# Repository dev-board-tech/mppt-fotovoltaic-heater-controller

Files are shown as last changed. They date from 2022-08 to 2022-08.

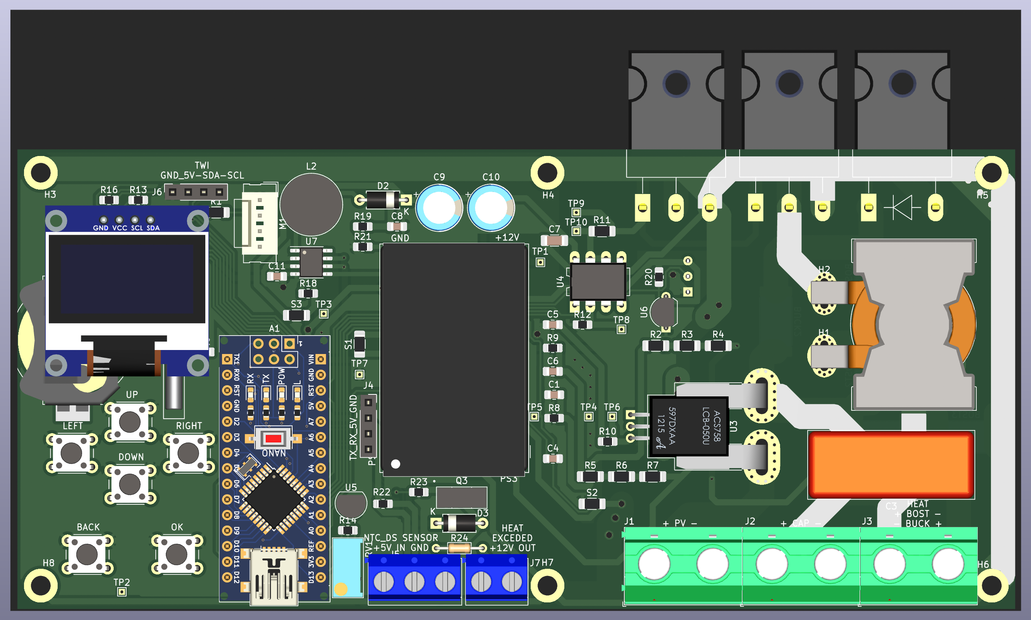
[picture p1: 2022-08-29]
resource/MPPT-Controller-TOP-Assembly.png

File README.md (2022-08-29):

# MPPT Fotovoltaic Heater Controller
 A compact fotovoltaic high power high voltage MPPT heater controller

A very compact heater controller that uses fotovoltaic panels in order to heat water in a boiler.

The project is developed around an Arduino nano V3 module using a BW OLED 128x64 SPI or TWI display.

The controller is designed to be configured working in BUCK or BOST mode thru changing the location of three jumpers.

The BUCK/BOST coil can be mounted externally using screws, the same the PV input capacitor, this allow for the board to be more compact decreasing the production price.

Include:

* One fan PWM output.
* Two onboard digital temperature sensors DS18B20.
* One wired NTC 10K temperature sensor wired to the heater.
* Onboard voltage reference TL431LP.
* Dedicated current sensor ACS758xCB-100B-PFF.
* One temperature exceeded output terminal.
* One RTC with backup battery because the controller is powered exclusively from panels DS1307.
* UART connector with 5V power.
* TWI connector with 5V power.
* Support three models of dedicated AC-DC/DC-DC inverter 95-385V to 9-12V for powering the board from panels HLK-PM12/HLK-5M12/RAC04-12SGA.
* BUCK inverter from 9-12V to 15-18V to efficiently drive the gate of the power MOS/IGBT MC34063AD.

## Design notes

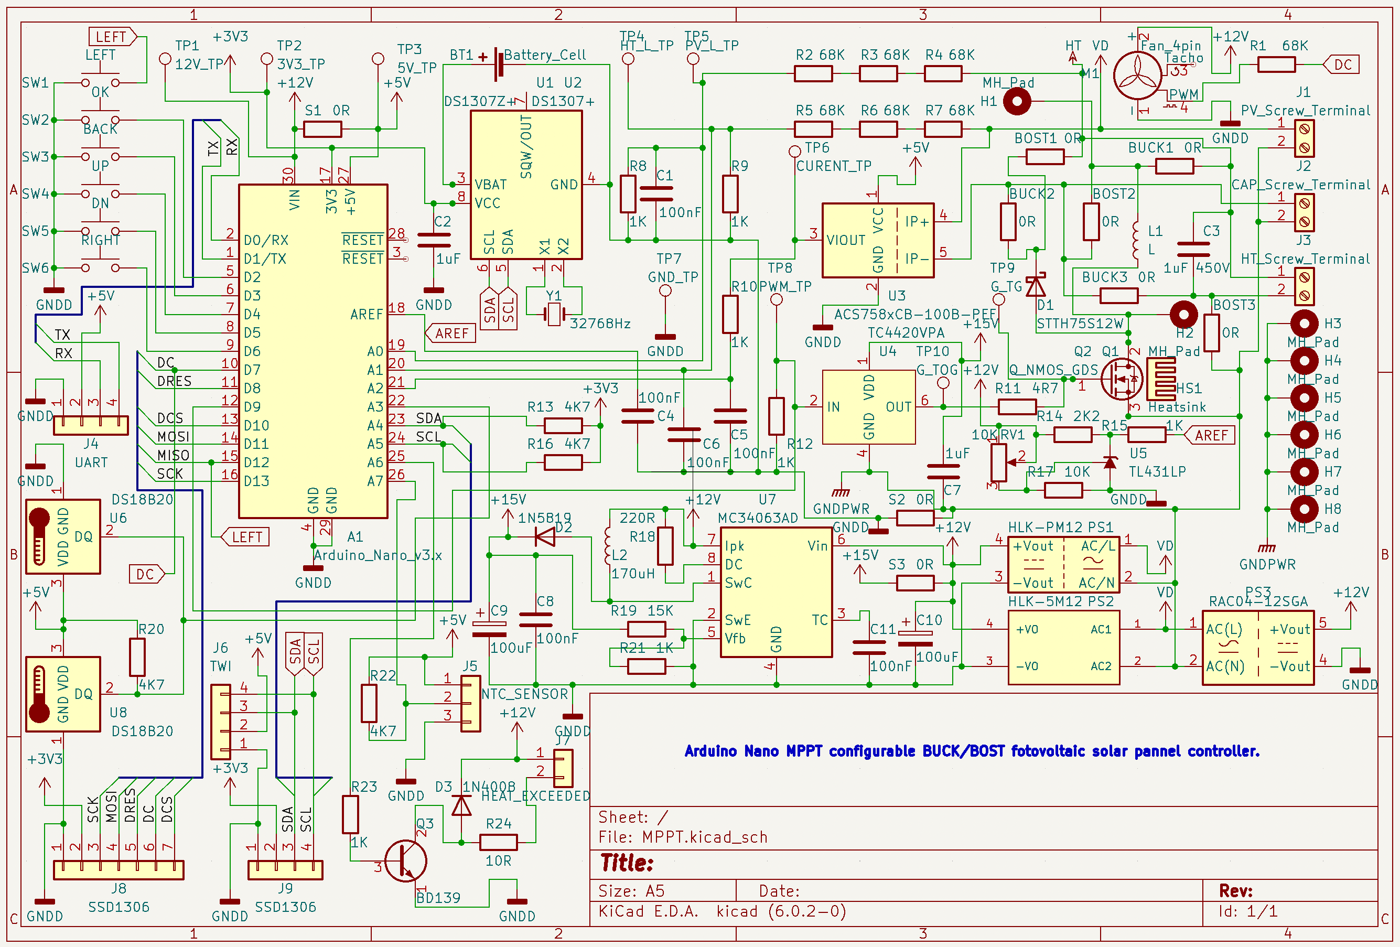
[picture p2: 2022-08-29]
resource/MPPT-Controller-SCH.png

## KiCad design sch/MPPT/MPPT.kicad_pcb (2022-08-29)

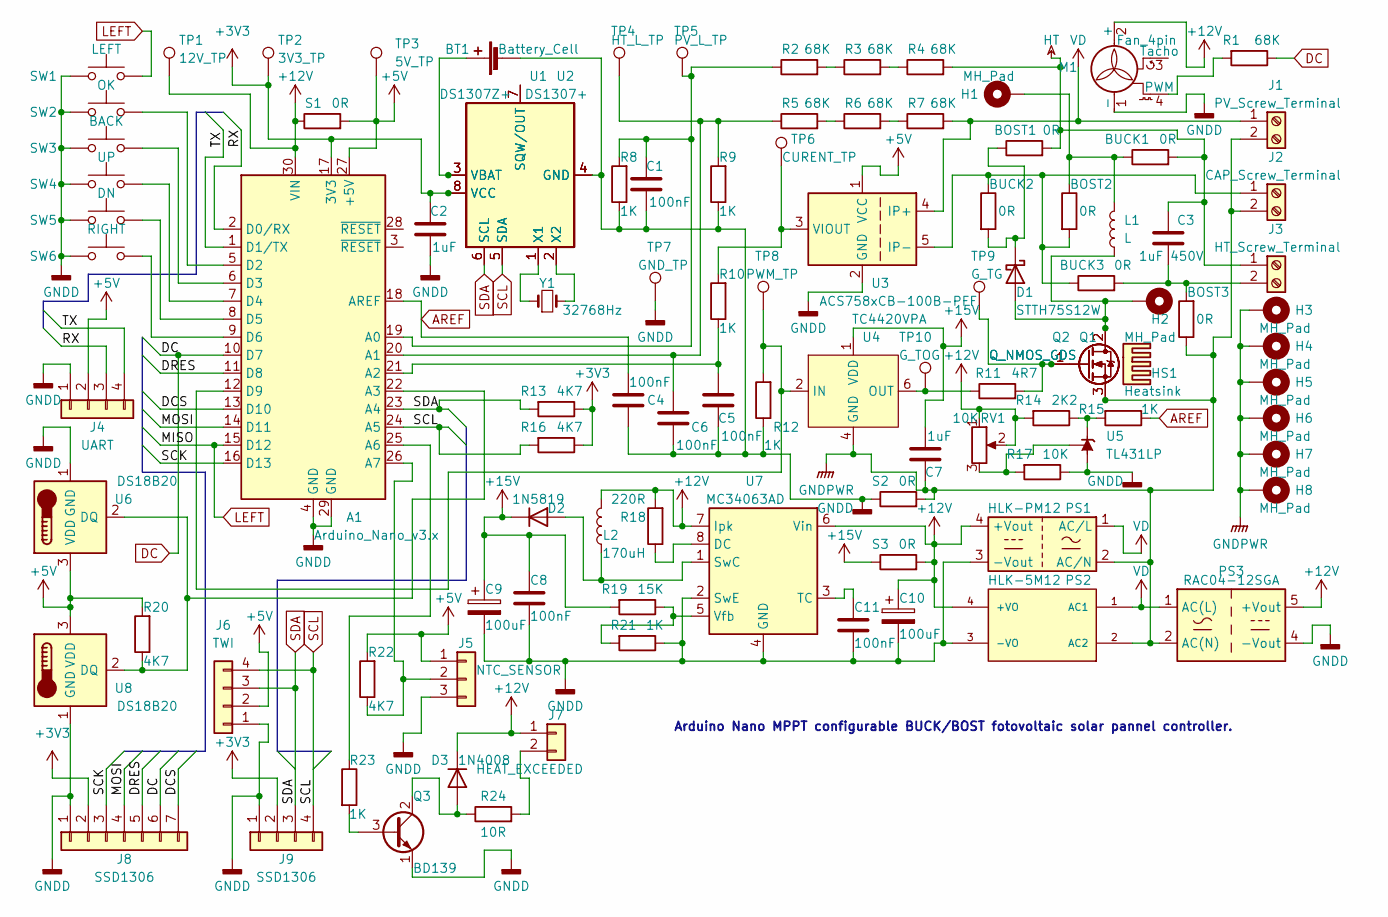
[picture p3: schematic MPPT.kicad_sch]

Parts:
A1: Arduino_Nano_v3.x; Arduino_Nano
BOST1, BOST2, BOST3: 0R; R_4020_10251Metric_Pad1.65x5.30mm_HandSolder
BT1: Battery_Cell; BatteryHolder_MPD_BC2003_1x2032
BUCK1, BUCK2, BUCK3: 0R; R_4020_10251Metric_Pad1.65x5.30mm_HandSolder
C1, C4, C5, C6, C8, C11: 100nF; C_0805_2012Metric_Pad1.18x1.45mm_HandSolder
C2: 1uF; C_0805_2012Metric_Pad1.18x1.45mm_HandSolder
C3: 1uF 450V; C_Rect_L27.0mm_W11.0mm_P22.00mm
C7: 1uF; C_1206_3216Metric_Pad1.33x1.80mm_HandSolder
C9, C10: 100uF; CP_Radial_D7.5mm_P2.50mm
D1: STTH75S12W; D_DO-247_Horizontal_TabDown
D2: 1N5819; D_A-405_P7.62mm_Horizontal
D3: 1N4008; D_A-405_P7.62mm_Horizontal
H1, H2, H3, H4, H5, H6, H7, H8: MH_Pad; MountingHole_3.2mm_M3_ISO14580_Pad_TopBottom
HS1: Heatsink; Heatsink_AAVID_TV5G_TO220_Horizontal
J1: PV_Screw_Terminal; TerminalBlock_MetzConnect_Type703_RT10N02HGLU_1x02_P9.52mm_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
J2: CAP_Screw_Terminal; TerminalBlock_MetzConnect_Type703_RT10N02HGLU_1x02_P9.52mm_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
J3: HT_Screw_Terminal; TerminalBlock_MetzConnect_Type703_RT10N02HGLU_1x02_P9.52mm_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
J4: UART; PinSocket_1x04_P2.54mm_Vertical
J5: NTC_SENSOR; TerminalBlock_bornier-3_P5.08mm
J6: TWI; PinSocket_1x04_P2.54mm_Vertical
J7: HEAT_EXCEEDED; TerminalBlock_bornier-2_P5.08mm
J8: SSD1306; PinSocket_1x07_P2.54mm_Vertical
J9: SSD1306; PinSocket_1x04_P2.54mm_Vertical
L1: L; HXX40A1.5uH
L2: 170uH; L_Radial_D10.0mm_P5.00mm_Fastron_07M
M1: Fan_4pin; Molex_SL_171971-0004_1x04_P2.54mm_Vertical
PS1: HLK-PM12; Converter_ACDC_HiLink_HLK-PMxx
PS2: HLK-5M12; CONV_HLK-5M05; PARTREV N/A
PS3: RAC04-12SGA; Converter_ACDC_RECOM_RAC04-xxSGx_THT
Q1, Q2: Q_NMOS_GDS; TO-247-3_Horizontal_TabDown
Q3: BD139; TO-126-3_Vertical
R1, R2, R3, R4, R5, R6, R7: 68K; R_1206_3216Metric_Pad1.30x1.75mm_HandSolder
R8, R9, R10, R12, R15, R21, R23: 1K; R_0805_2012Metric_Pad1.20x1.40mm_HandSolder
R11: 4R7; R_1206_3216Metric_Pad1.30x1.75mm_HandSolder
R13, R16, R20, R22: 4K7; R_0805_2012Metric_Pad1.20x1.40mm_HandSolder
R14: 2K2; R_0805_2012Metric_Pad1.20x1.40mm_HandSolder
R17: 10K; R_0805_2012Metric_Pad1.20x1.40mm_HandSolder
R18: 220R; R_0805_2012Metric_Pad1.20x1.40mm_HandSolder
R19: 15K; R_0805_2012Metric_Pad1.20x1.40mm_HandSolder
R24: 10R; R_Axial_DIN0204_L3.6mm_D1.6mm_P7.62mm_Horizontal
RV1: 10K; Potentiometer_Bourns_3296W_Vertical
S1, S2, S3: 0R; R_1206_3216Metric_Pad1.30x1.75mm_HandSolder
SW1: LEFT; SW_PUSH_6mm_H13mm
SW2: OK; SW_PUSH_6mm_H13mm
SW3: BACK; SW_PUSH_6mm_H13mm
SW4: UP; SW_PUSH_6mm_H13mm
SW5: DN; SW_PUSH_6mm_H13mm
SW6: RIGHT; SW_PUSH_6mm_H13mm
TP1: 12V_TP; TestPoint_THTPad_1.0x1.0mm_Drill0.5mm
TP2: 3V3_TP; TestPoint_THTPad_1.0x1.0mm_Drill0.5mm
TP3: 5V_TP; TestPoint_THTPad_1.0x1.0mm_Drill0.5mm
TP4: HT_L_TP; TestPoint_THTPad_1.0x1.0mm_Drill0.5mm
TP5: PV_L_TP; TestPoint_THTPad_1.0x1.0mm_Drill0.5mm
TP6: CURENT_TP; TestPoint_THTPad_1.0x1.0mm_Drill0.5mm
TP7: GND_TP; TestPoint_THTPad_1.0x1.0mm_Drill0.5mm
TP8: PWM_TP; TestPoint_THTPad_1.0x1.0mm_Drill0.5mm
TP9: G_TG; TestPoint_THTPad_1.0x1.0mm_Drill0.5mm
TP10: G_TOG; TestPoint_THTPad_1.0x1.0mm_Drill0.5mm
U1: DS1307+; DIP-8_W7.62mm
U2: DS1307Z+; SOIC-8_3.9x4.9mm_P1.27mm
U3: ACS758xCB-100B-PFF; Allegro_CB_PFF
U4: TC4420VPA; DIP-8_W7.62mm_LongPads
U5: TL431LP; TO-92_Inline
U6, U8: DS18B20; TO-92_Inline_Wide
U7: MC34063AD; SOIC-8_3.9x4.9mm_P1.27mm
Y1: 32768Hz; Crystal_AT310_D3.0mm_L10.0mm_Horizontal

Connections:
+3V3: A1.17 (3V3), C2.2, J8.2, J9.2, R13.1, R16.1, TP2.1, U1.8 (VCC), U2.8 (VCC)
+5V: A1.27 (+5V), J4.2, J5.1, J6.2, R20.2, R22.2, S1.2, TP3.1, U3.1 (VCC), U6.3 (VDD), U8.3 (VDD)
+12V: A1.30 (VIN), C10.1, D3.1 (K), J7.1, L2.2, M1.2 (+), PS1.4 (+Vout), PS2.4 (+VO), PS3.5 (+Vout), R14.2, R18.2, RV1.1, RV1.2, S1.1, S3.2, TP1.1, U7.6 (Vin), U7.7 (Ipk)
+15V: C7.2, C8.1, C9.1, D2.1 (K), R19.2, S3.1, U4.1 (VDD), U4.8 (VDD)
/DCS: A1.13 (D10), J8.7
/DRES: A1.11 (D8), J8.5
/MOSI: A1.14 (D11), J8.4
/RX: A1.2 (D0/RX), J4.3
/SCK: A1.16 (D13), J8.3
/TX: A1.1 (D1/TX), J4.4
AREF: A1.18 (AREF), C4.1, R15.1
DC: A1.10 (D7), J8.6, R1.1
GNDD: A1.4 (GND), A1.29 (GND), BT1.2 (-), C1.1, C2.1, C4.2, C5.1, C6.1, C8.2, C9.2, C10.2, C11.2, J4.1, J5.3, J6.1, J8.1, J9.1, M1.1 (-), PS1.3 (-Vout), PS2.3 (-VO), PS3.4 (-Vout), Q3.1 (E), R8.1, R9.1, R12.1, R17.1, R21.1, S2.1, SW1.1, SW2.1, SW3.1, SW4.1, SW5.1, SW6.1, TP7.1, U1.4 (GND), U2.4 (GND), U3.2 (GND), U5.2 (A), U6.1 (GND), U7.2 (SwE), U7.4 (GND), U8.1 (GND)
GNDPWR: BOST3.1, C7.1, H3.1, H4.1, H5.1, H6.1, H7.1, H8.1, J1.2, J2.2, PS1.2 (AC/N), PS2.2 (AC2), PS3.2 (AC(N)), Q1.3 (S), Q2.3 (S), S2.2, U4.4 (GND), U4.5 (GND)
HT: BOST1.2, BUCK1.2, C3.2, J3.1, R4.2
LEFT: A1.15 (D12), SW1.2
unnamed: A1.5 (D2), SW2.2
unnamed: A1.6 (D3), SW3.2
unnamed: A1.7 (D4), SW4.2
unnamed: A1.8 (D5), SW5.2
unnamed: A1.9 (D6), SW6.2
unnamed: A1.12 (D9), R12.2, TP8.1, U4.2 (IN)
unnamed: A1.19 (A0), C1.2, R2.1, R8.2, TP5.1
unnamed: A1.20 (A1), C6.2, R5.1, R9.2, TP4.1
unnamed: A1.21 (A2), C5.2, R10.1
unnamed: A1.22 (A3), R20.1, U6.2 (DQ), U8.2 (DQ)
unnamed: A1.25 (A6), R23.1
unnamed: A1.26 (A7), J5.2, R22.1
unnamed: BOST1.1, BUCK2.2, D1.1 (K)
unnamed: BOST2.1, BUCK1.1, H1.1, L1.2
unnamed: BOST2.2, BUCK2.1, BUCK3.1, J2.1, U3.5 (IP-)
unnamed: BOST3.2, BUCK3.2, C3.1, J3.2
unnamed: BT1.1 (+), U1.3 (VBAT), U2.3 (VBAT)
unnamed: C11.1, U7.3 (TC)
unnamed: D1.2 (A), H2.1, L1.1, Q1.2 (D), Q2.2 (D)
unnamed: D2.2 (A), L2.1, U7.1 (SwC)
unnamed: D3.2 (A), Q3.2 (C), R24.1
unnamed: J7.2, R24.2
unnamed: M1.4 (PWM), R1.2
unnamed: Q1.1 (G), Q2.1 (G), R11.2, TP9.1
unnamed: Q3.3 (B), R23.2
unnamed: R2.2, R3.1
unnamed: R3.2, R4.1
unnamed: R5.2, R6.1
unnamed: R6.2, R7.1
unnamed: R10.2, TP6.1, U3.3 (VIOUT)
unnamed: R11.1, TP10.1, U4.6 (OUT), U4.7 (OUT)
unnamed: R14.1, R15.2, U5.3 (K)
unnamed: R17.2, RV1.3, U5.1 (REF)
unnamed: R18.1, U7.8 (DC)
unnamed: R19.1, R21.2, U7.5 (Vfb)
unnamed: U1.1 (X1), U2.1 (X1), Y1.1
unnamed: U1.2 (X2), U2.2 (X2), Y1.2
unnamed: U1.7 (SQW/OUT), U2.7 (SQW/OUT)
SCL: A1.24 (A5), J6.4, J9.4, R16.2, U1.5 (SDA), U2.5 (SDA)
SDA: A1.23 (A4), J6.3, J9.3, R13.2, U1.6 (SCL), U2.6 (SCL)
VD: J1.1, PS1.1 (AC/L), PS2.1 (AC1), PS3.1 (AC(L)), R7.2, U3.4 (IP+)

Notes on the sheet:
Arduino Nano MPPT configurable BUCK/BOST fotovoltaic solar pannel controller.

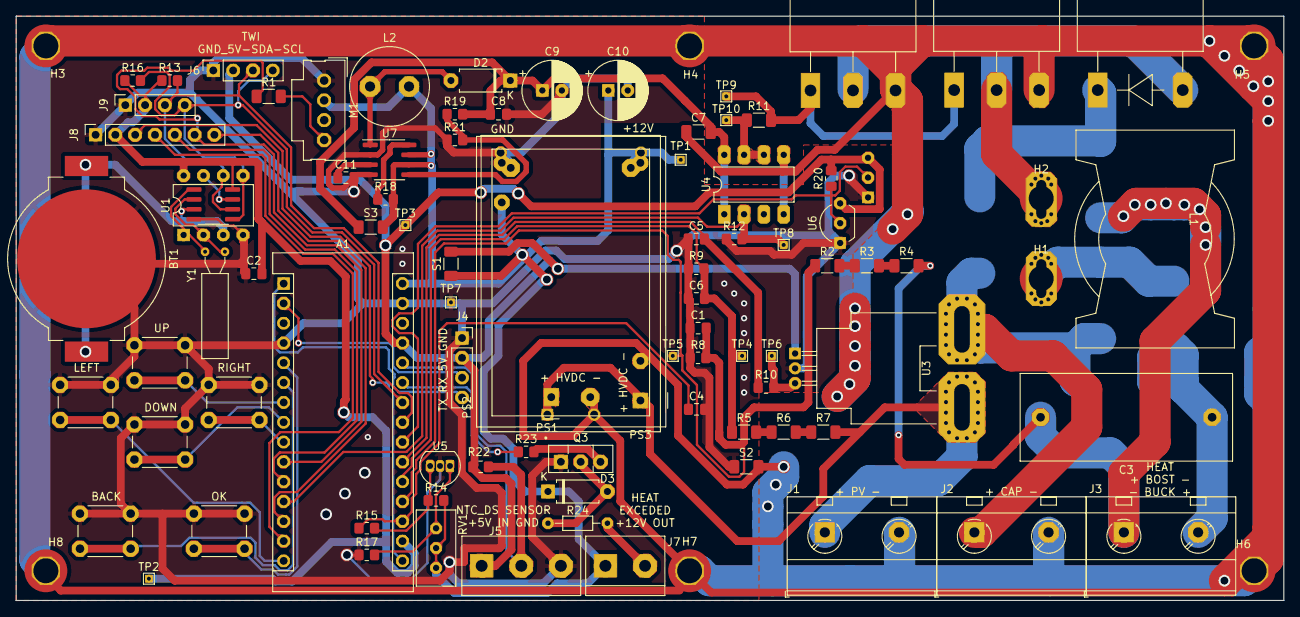
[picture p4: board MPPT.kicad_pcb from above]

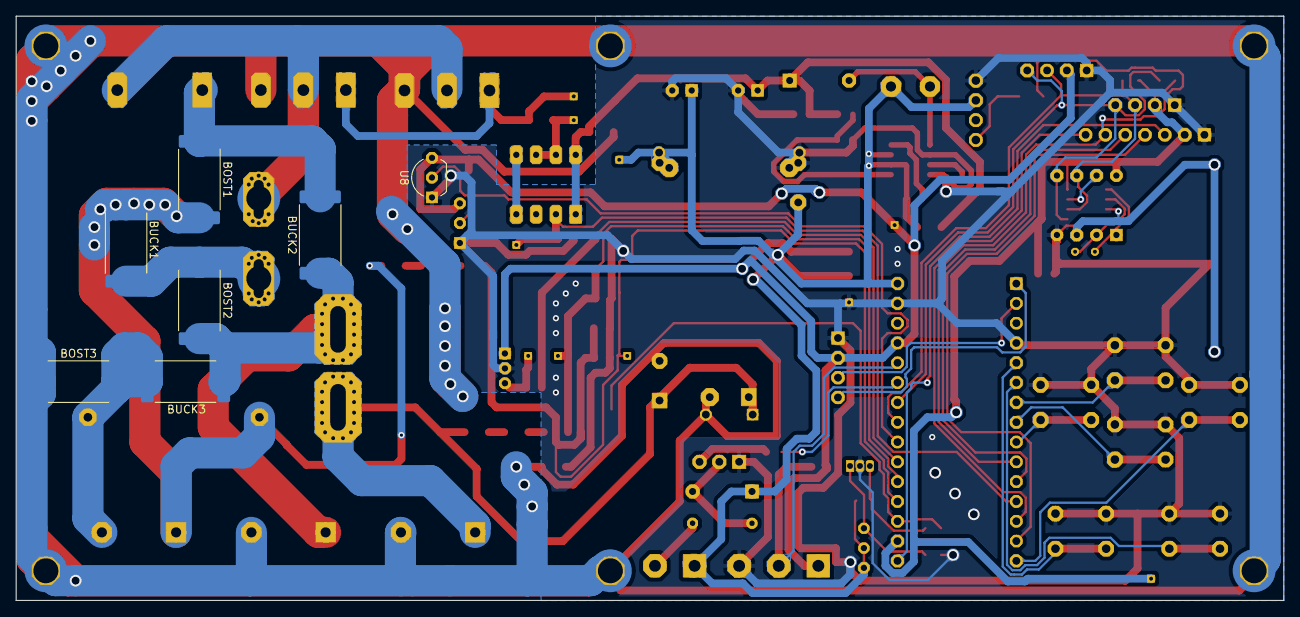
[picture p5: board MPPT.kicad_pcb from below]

Board: 2 copper layers, 162.6 x 74.9 mm, 102 parts (7 on the bottom side), 57 nets.

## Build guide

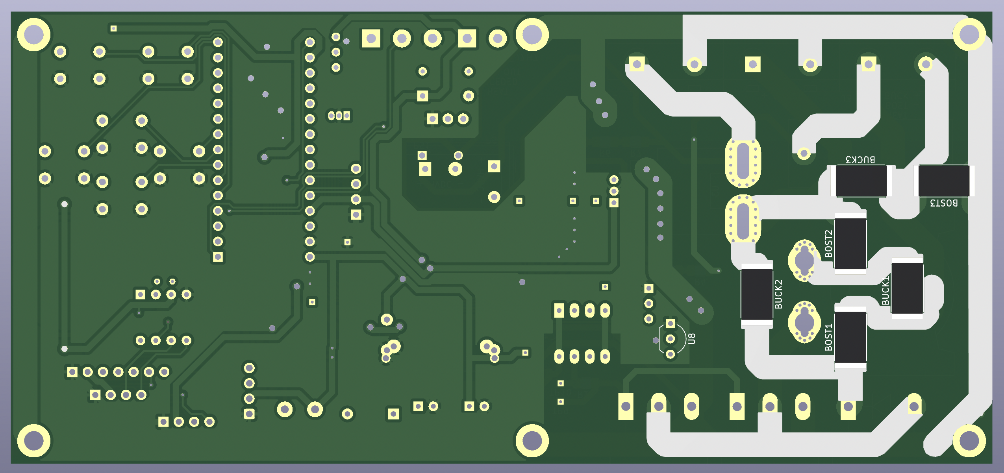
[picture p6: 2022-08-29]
resource/MPPT-Controller-BOT-Assembly.png
